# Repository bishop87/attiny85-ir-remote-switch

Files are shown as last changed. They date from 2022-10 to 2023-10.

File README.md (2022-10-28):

# attiny85-ir-remote-switch

Simple circuit used to create a programmable ir receiver to control a power mosfet as a led light switch.

### Hardware:
* AtTiny85
* Mosfet IRLB8721 (you can use any 5V mosfet)
* LM7805 as voltage regulator
* TSOP1836 as IR Receiver module
* capacitors (see schematic)
* resistors (see schematic)
* 2x tactile switches
* led (used to get feedback about IR command)
* 2x 2PIN connector (for mail voltage input and led strip output)

### PCB
in gerber folder you can find all files to create a working PCB

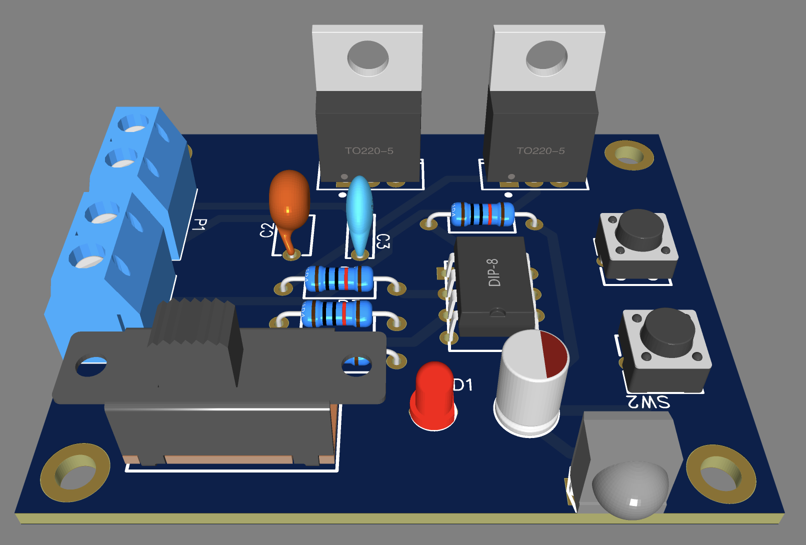
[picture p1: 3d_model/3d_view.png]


### 3D Case
in 3d_model folder you can find stl files about my 3D case design

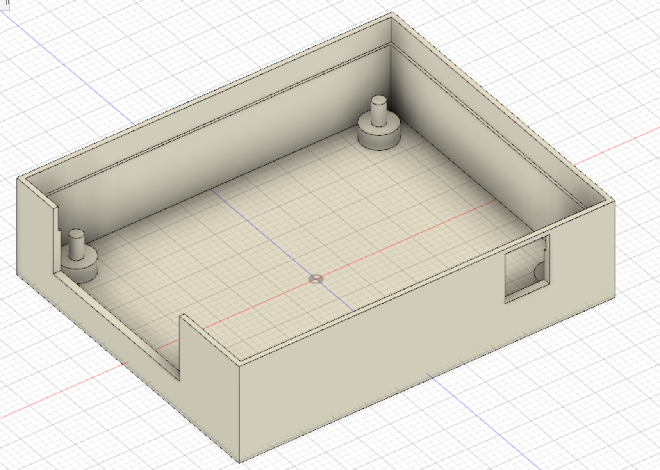
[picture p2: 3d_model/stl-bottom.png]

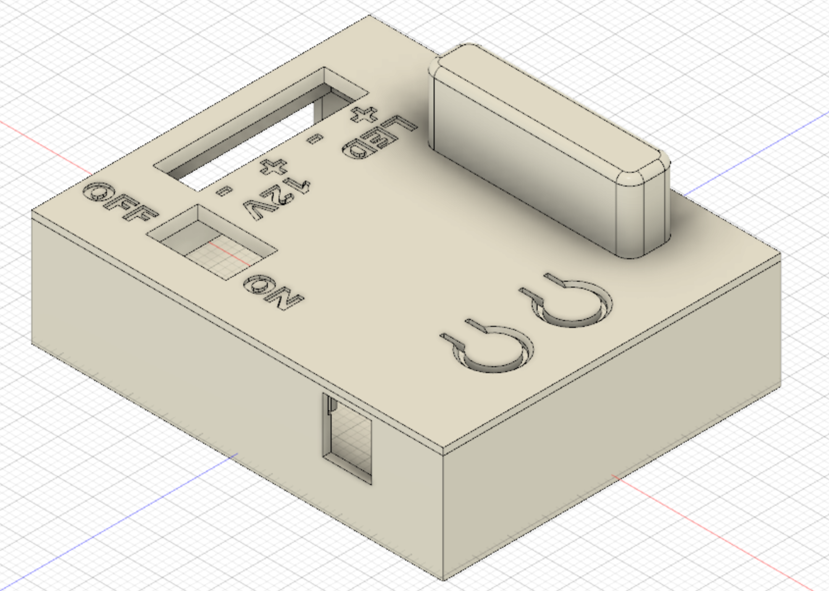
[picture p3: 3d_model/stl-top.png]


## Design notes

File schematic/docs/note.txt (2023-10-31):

- selezionare come scheda: "ATtiny25/45/85 (No bootloader)"
- selezionare come programmatore: "Arduino as ISP"
- la prima volta premere: Scrivi il bootloader (questo non scrive realmente il bootloader, ma imposta i fusibili interni per operare a 8Mhz)
- a questo punto si può caricare lo sketch

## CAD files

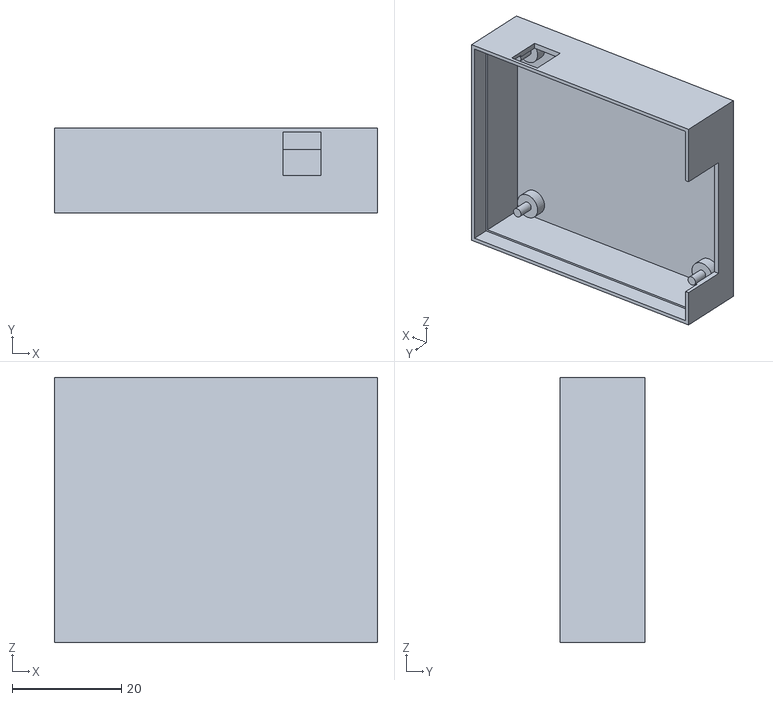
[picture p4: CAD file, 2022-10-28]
3d_model/ir_switch_case_ir_switch_case v3_bottom.stl
59.1 x 15.6 x 48.5

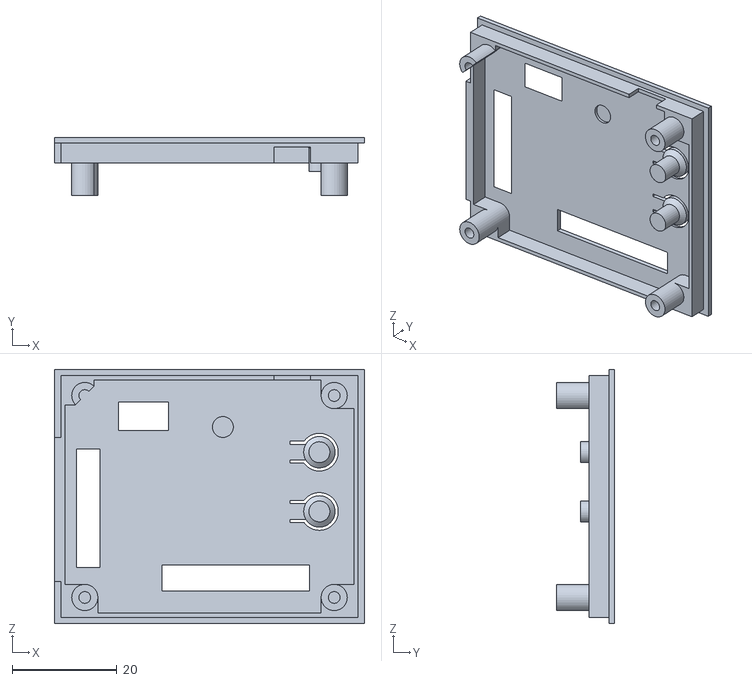
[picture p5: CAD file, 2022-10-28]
3d_model/ir_switch_case_ir_switch_case v3_top_1.stl
59.1 x 11.0 x 48.5

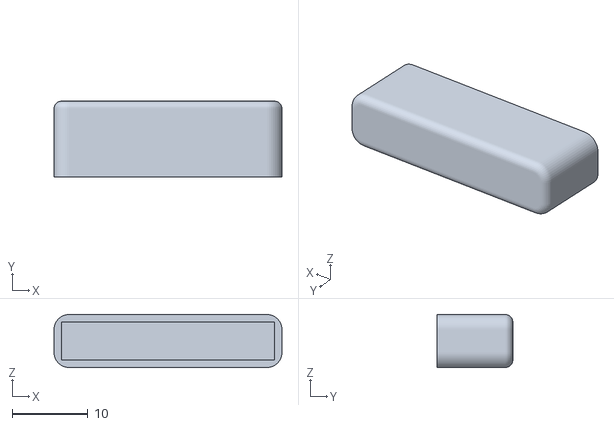
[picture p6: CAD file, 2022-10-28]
3d_model/ir_switch_case_ir_switch_case v3_top_2.stl
30.1 x 10.0 x 7.00

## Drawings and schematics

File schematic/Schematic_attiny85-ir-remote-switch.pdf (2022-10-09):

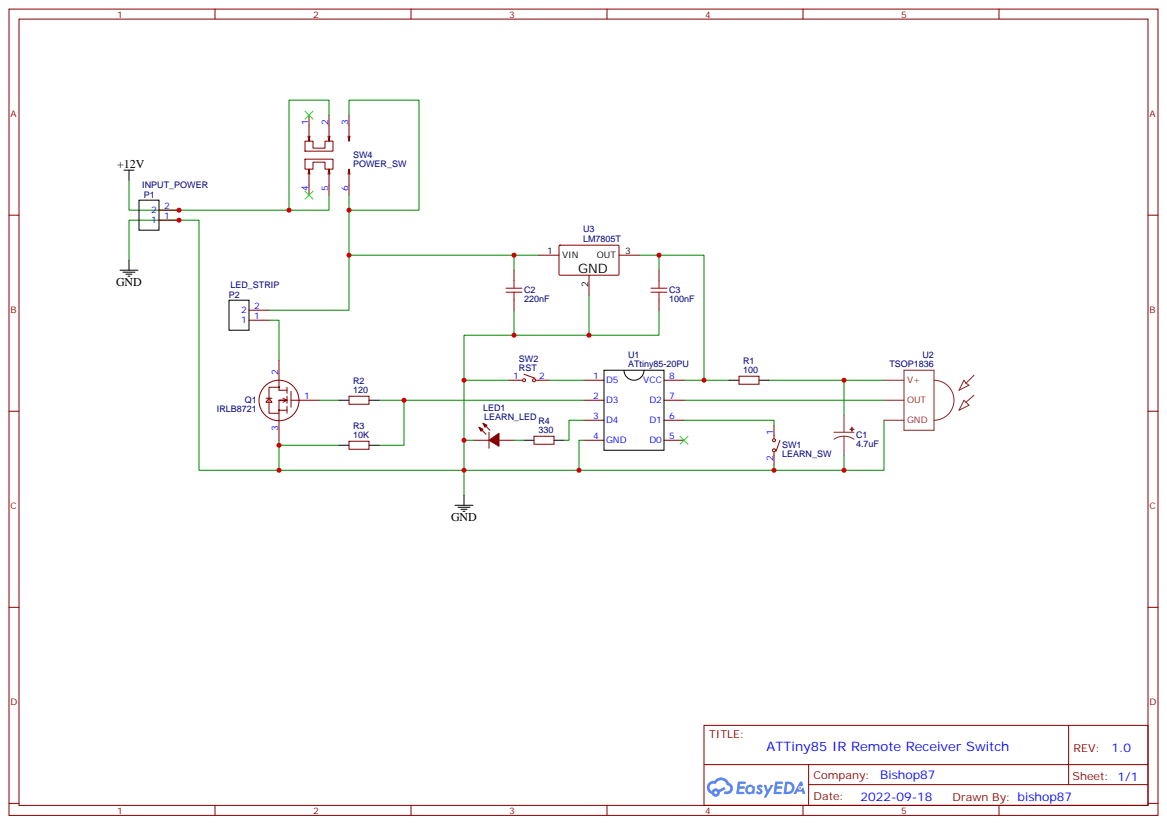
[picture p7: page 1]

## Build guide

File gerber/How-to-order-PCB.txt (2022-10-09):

How to Order PCB

Please refer to:
https://docs.easyeda.com/en/PCB/Order-PCB

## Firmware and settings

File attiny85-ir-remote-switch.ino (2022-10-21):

#include <IRremote.h>
#include <EEPROM.h>

#define IR_RECEIVE_PIN 2
#define IR_LEARN_SW 1
#define IR_LEARN_LED 4

#define OUT_PIN 3

byte outState = LOW;

int addr = 0;
bool learn = false;
int ir_code = -1;

void setup() {
  //Serial.begin(115200);

  pinMode(IR_LEARN_SW,  INPUT_PULLUP);
  pinMode(IR_LEARN_LED, OUTPUT);  
  pinMode(OUT_PIN,      OUTPUT); 
  digitalWrite(IR_LEARN_LED, LOW);
  ledBlink(1, 100, LOW);
  
  if(digitalRead(IR_LEARN_SW)==LOW){
    learn = true;  
    digitalWrite(IR_LEARN_LED, HIGH);
    //Serial.println("attivo learn mode!");
    IrReceiver.begin(IR_RECEIVE_PIN);
  }else{
    learn = false;
    ir_code = EEPROM.read(addr);
    //Serial.print("leggo ir_code: ");
    //Serial.println(ir_code);
    IrReceiver.begin(IR_RECEIVE_PIN);
  }
  

}

void loop() {
  if (IrReceiver.decode()) {
    int command = IrReceiver.decodedIRData.command;
    //Serial.println(command);
    
    if(learn){
      EEPROM.write(addr, command);
      ledBlink(5, 100, HIGH);
      //Serial.print("scrivo ir_code: ");
      //Serial.println(command);
    }else if(command == ir_code){
      outState = (outState == LOW) ? HIGH : LOW;
      digitalWrite(OUT_PIN, outState);
      ledBlink(1, 100, LOW);
      //Serial.print("setto pin uscita: ");
      //Serial.println(outState);
      delay(1000);
    }            
    IrReceiver.resume();        
  }
}

void ledBlink(int i, int d, int final_state){
  for(int k=0; k<i; ++k){
        delay(d);
        digitalWrite(IR_LEARN_LED, LOW==final_state);
        delay(d);
        digitalWrite(IR_LEARN_LED, HIGH==final_state);
      }
}

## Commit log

2022-09-18 added led status to code
2022-10-09 update pin number and blink stage
2022-10-09 added schematics, 3d model and gerber files
    [Drill_PTH_Through.DRL, Gerber_BoardOutlineLayer.GKO, Gerber_BottomLayer.GBL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]
2022-10-21 updated pins according to schematic
2022-10-28 added docs and readme
    [ir_switch_case_ir_switch_case v3_bottom.stl, ir_switch_case_ir_switch_case v3_top_1.stl, ir_switch_case_ir_switch_case v3_top_2.stl]
2023-10-31 notes about arduino as programmer added
